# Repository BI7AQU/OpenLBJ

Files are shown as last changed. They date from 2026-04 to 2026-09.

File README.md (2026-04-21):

# [OpenLBJ](https://github.com/BI7AQU/OpenLBJ)
- A LBJ message receiver based on ESP32-PICO-D4 and [Ai-Thinker Ra-01H](https://docs.ai-thinker.com/en/Ra-01H/index.html) (SX1276 RF chip).
- This project aims to receive the Chinese Railway Train Proximity Alarm (on 821.2375MHz following POCSAG protocol) messages transmitted by on board LBJ systems through CIR.
- This hardware is designed to be compatible with the **[SX1276_Receive_LBJ](https://github.com/FLN1021/SX1276_Receive_LBJ)** firmware.
- The design of this project is based on the [TTGO LoRa32 ESP32 dev board](https://github.com/Xinyuan-LilyGO/LilyGo-LoRa-Series/blob/master/schematic/T3_V1.6.1.pdf), and it integrates the functions of real-time clock (RTC), button menu and buzzer alarm.

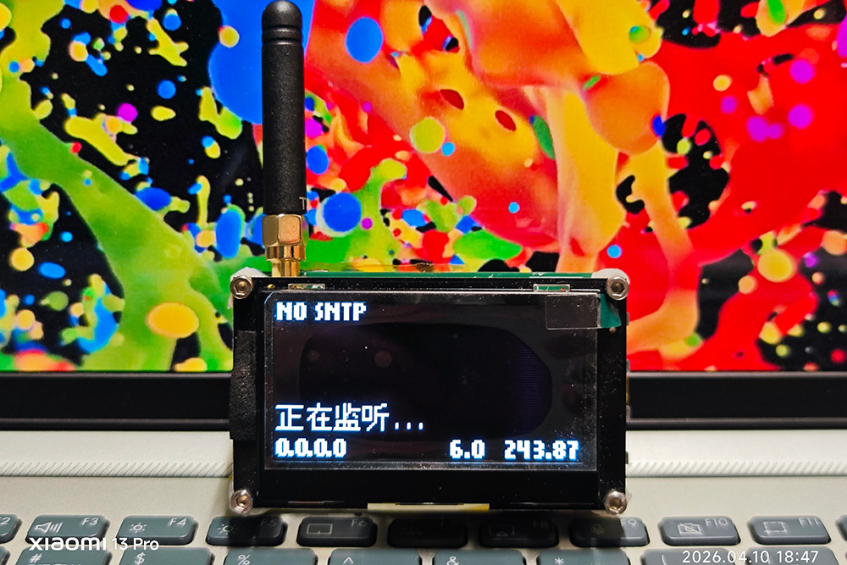
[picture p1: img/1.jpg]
Receiving...


## Notice

This project is intended for learning 2FSK signal reception modulation and POCSAG code decoding.

Please ensure that this complies with local laws and regulations when in use, and assume responsibility for any risks.

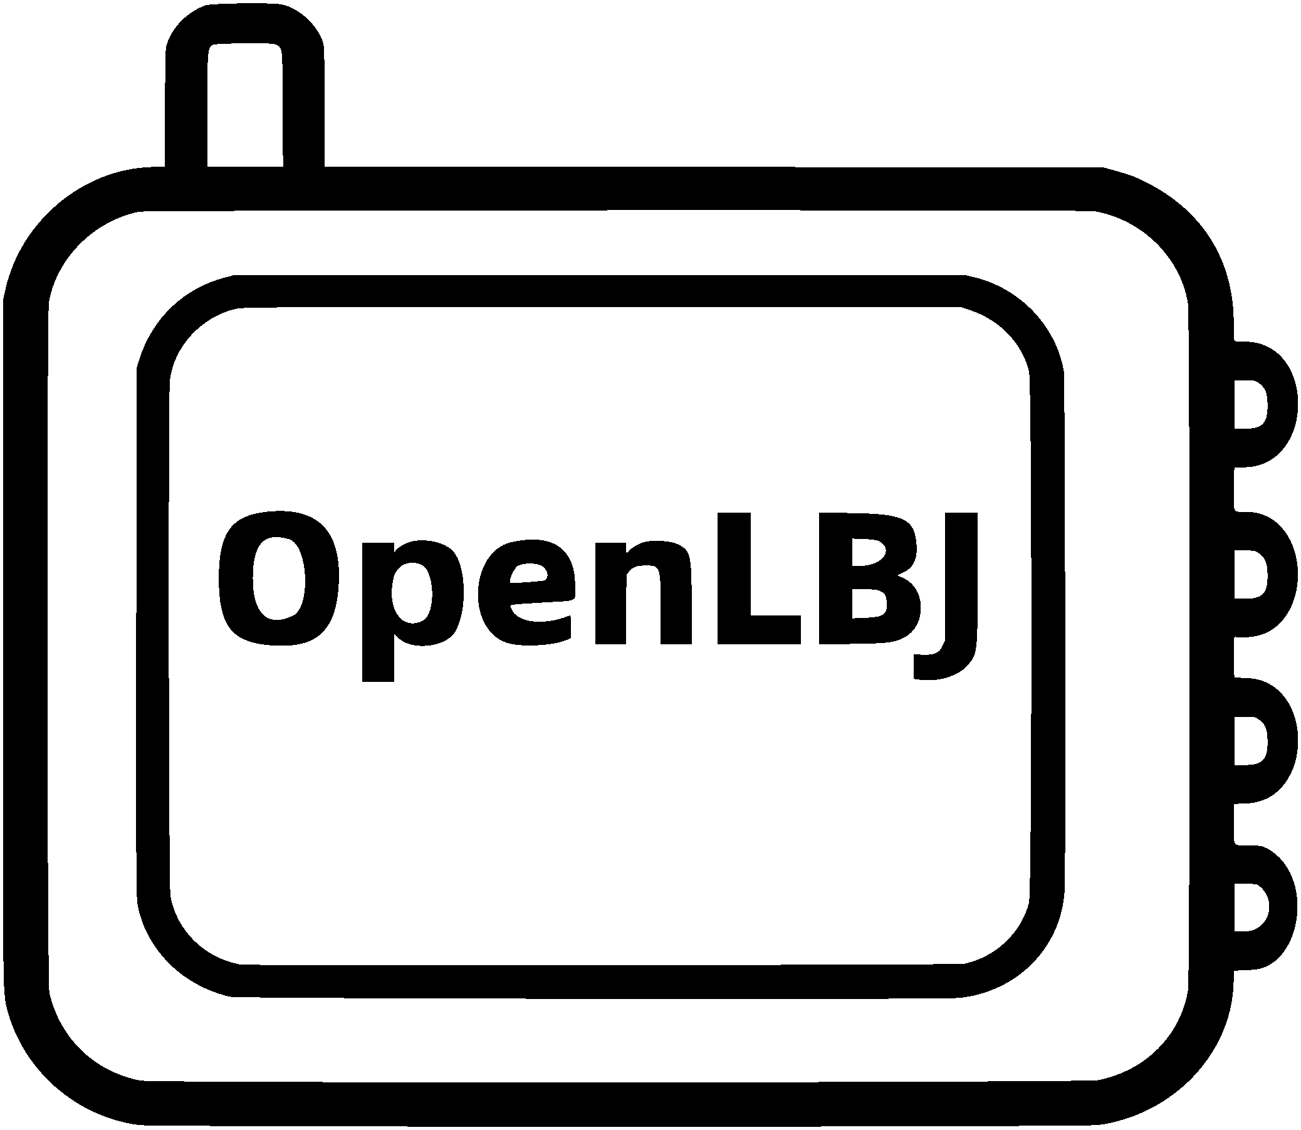
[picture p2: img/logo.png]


## Hardware
The schematic of this board can be found in the folder.

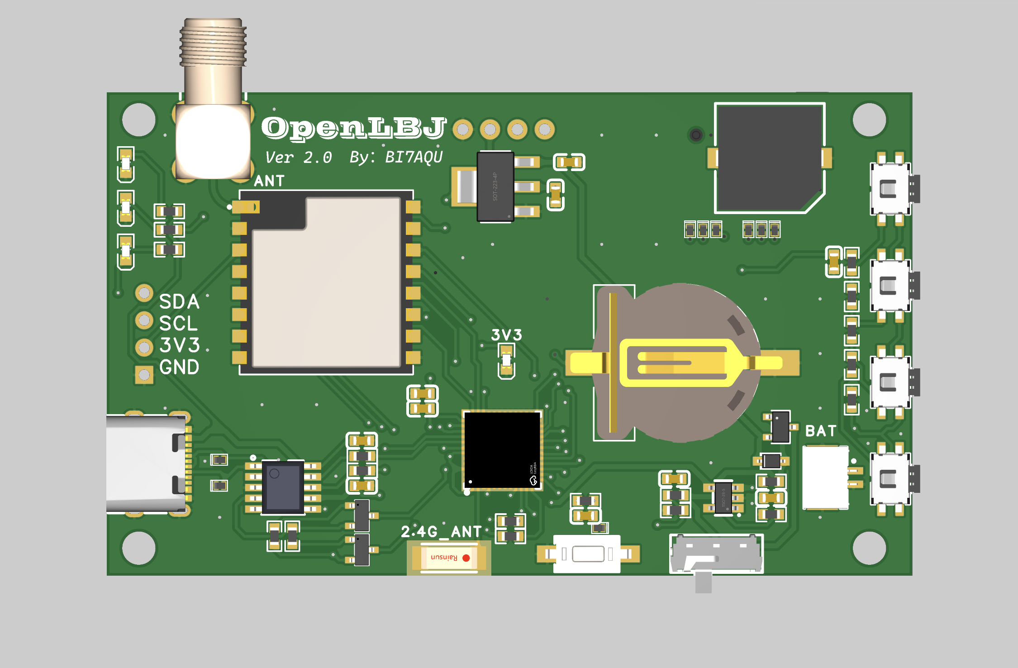
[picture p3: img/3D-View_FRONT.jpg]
Front


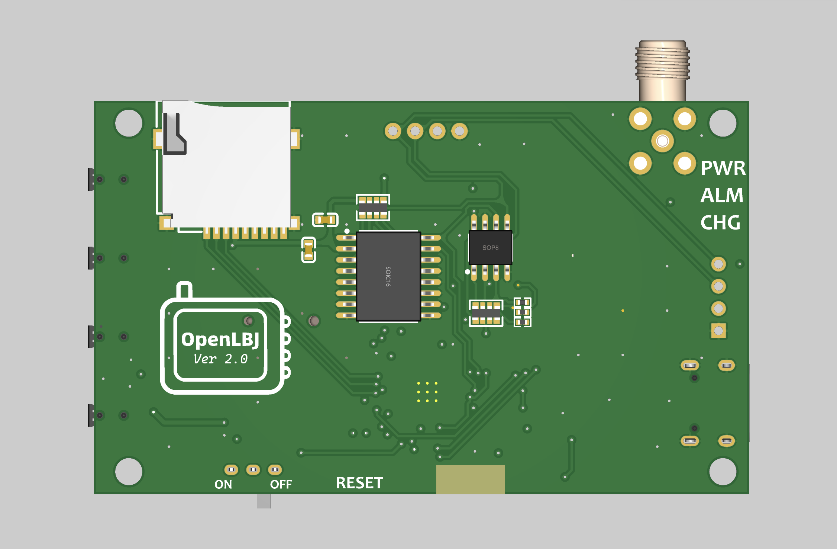
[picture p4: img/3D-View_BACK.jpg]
Back


## Known Issues
- Takes a very long time to startup if a large number of files are in TF card.
- TF card hot-plug is **NOT** supported. Unplug while power on will cause crash after next message receive.
- Partially decoded or corrupted message will show on display.

Sometimes the received messages may be corrupt, partially decoded or wrongly corrected, thus may display unreliable results.
If `<NUL>`, `NA`, `********` or part of these characters shows up, it means this part of the message is corrupted.

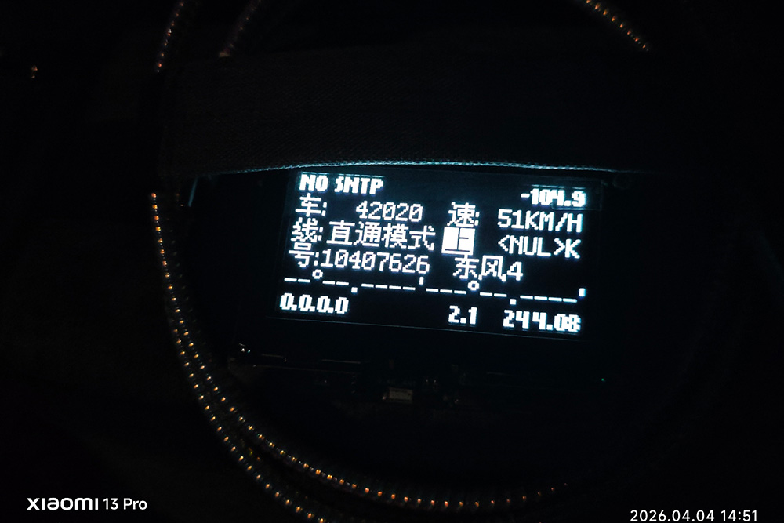
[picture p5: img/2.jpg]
Decoding...


## License
[GPL-3.0 license](https://github.com/BI7AQU/OpenLBJ#GPL-3.0-1-ov-file)

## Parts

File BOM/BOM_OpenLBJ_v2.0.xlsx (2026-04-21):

烧录说明：按键需调试修改主程序中ADC值。
焊接说明：1、若无需RTC功能，正面电池和背面除TF卡座以外的元器件均不焊接；2、ULC0511二极管可不焊；3、两种OLED屏幕二选一即可。
No. | Quantity | Comment | Designator | Footprint | Value | Manufacturer Part | Manufacturer | Supplier Part
1 | 1 | CR1220-2 | B1 | BAT-SMD_CR1220-2 |  | CR1220-2 | QIJEY | C70381
2 | 8 | 100nF | C1,C3,C4,C5,C6,C7,C10,C12 | C0603 | 100nF | CC0603KRX7R9BB104 | YAGEO(国巨) | C14663
3 | 3 | 10uF | C2,C9,C11 | C0603 | 10uF | CC0603KRX5R6BB106 | YAGEO(国巨) | C326057
4 | 1 | 1uF | C8 | C0603 | 1uF | CC0603KRX5R8BB105 | YAGEO(国巨) | C14664
5 | 1 | WAFER-GH1.25-2PWB | CN1 | CONN-TH_2P-P1.25_XUNPU_WAFER-GH1.25-2PWB |  | WAFER-GH1.25-2PWB | XUNPU(讯普) | C3029377
6 | 9 | ULC0511CDN | D1,D2,D3,D4,D5,D6,D7,D8,D9 | X1-DFN1006-2_L1.0-W0.6-RD |  | ULC0511CDN | Leiditech(雷卯电子) | C384841
7 | 1 | BAT20JFILM | D10 | SOD-323_L1.8-W1.3-LS2.5-RD |  | BAT20JFILM | ST(意法半导体) | C155590
8 | 1 | AN2051-245 | L1 | ANT2051 |  | AN2051-245 | Rainsun(霖昱微) | C99727
9 | 4 | GL0603UR01 | LED1,LED2,LED3,LED4 | LED0603-FD |  | GL0603UR01 | Guiguang light(桂光光电) | C51933292
10 | 1 | HS242L03W2C01 | OLED1 | LCD-TH_4P-L72.0-W43.0-P2.54_HS242L03W2C01 |  | HS242L03W2C01 | HS(汉昇) | C7466001
11 | 1 | HS96L03W2C03 | OLED2 | OLED-TH_L27.8-W27.2-P2.54_C9900033791 |  | HS96L03W2C03 | HS(汉昇) | C5248080
12 | 2 | S8050 | Q1,Q2 | SOT-23-3_L2.9-W1.3-P1.90-LS2.3-BR |  | S8050 | R+O(宏嘉诚) | C20069125
13 | 1 | SI2307A | Q3 | SOT-23-3_L3.0-W1.7-P0.95-LS2.9-BR |  | SI2307A | UMW(友台半导体) | C347490
14 | 2 | 470Ω | R1,R2 | R0603 | 470Ω | RC0603JR-07470RL | YAGEO(国巨) | C114433
15 | 6 | 10kΩ | R3,R6,R7,R15,R16,R17 | R0603 | 10kΩ | RC0603FR-0710KL | YAGEO(国巨) | C98220
16 | 2 | 22Ω | R4,R5 | R0603 | 22Ω | RC0603FR-0722RL | YAGEO(国巨) | C107701
17 | 2 | 2kΩ | R8,R9 | R0603 | 2kΩ | RC0603FR-072KL | YAGEO(国巨) | C105576
18 | 2 | 100kΩ | R10,R11 | R0603 | 100kΩ | RC0603FR-07100KL | YAGEO(国巨) | C14675
19 | 3 | 0Ω | R12,R13,R14 | R0402 | 0Ω | RC0402FR-070RL | YAGEO(国巨) | C106231
20 | 1 | 2kΩ | R18 | R0603 | 2kΩ | RC0603JR-072KL | YAGEO(国巨) | C105581
21 | 2 | 4.7kΩ | RN1,RN2 | RES-ARRAY-SMD_0603-8P-L3.2-W1.6-BL | 4.7kΩ | 4D03WGJ0472T5E | UNI-ROYAL(厚声) | C1980
22 | 1 | TS-1101-C-W | SW1 | SW-SMD_L6.0-W3.3-LS8.0 |  | TS-1101-C-W | XKB Connection(中国星坤) | C318938
23 | 1 | MK-12D18-G040 | SW2 | SW-TH_MK-12D18-G040 |  | MK-12D18-G040 | G-Switch(品赞) | C963202
24 | 4 | TS-3547SLM | SW7,SW8,SW9,SW10 | SW-SMD_TS-3547SLM |  | TS-3547SLM | 康深 | C47734524
25 | 1 | Ra-01H | U1 | WIRELM-SMD_RA-01H |  | Ra-01H | Ai-Thinker(安信可) | C503593
26 | 1 | ESP32-PICO-D4 | U2 | LGA-48_L7.0-W7.0-P0.50-BL-EP5.4 |  | ESP32-PICO-D4 | ESPRESSIF(乐鑫) | C193707
27 | 1 | HX TF PUSH | U3 | TF-SMD_TF-PUSH |  | HX TF PUSH | hanxia(韩下) | C5184837
28 | 1 | AMS1117-3.3 | U4 | SOT-223-4_L6.5-W3.5-P2.30-LS7.0-BR |  | AMS1117-3.3 | UMW(友台半导体) | C347222
29 | 1 | CH340K | U5 | ESOP-10_L4.9-W3.9-P1.00-LS6.2-BL-EP |  | CH340K | WCH(南京沁恒) | C968586
30 | 1 | TP4054 | U6 | TSOT-23-5_L2.9-W1.6-P0.95-LS2.8-BR |  | TP4054 | UMW(友台半导体) | C668215
31 | 1 | AT24C02 | U7 | SOP-8_L5.0-W4.0-P1.27-LS6.0-BL |  | AT24C02 | IDCHIP(英锐芯) | C688857
32 | 1 | 10GHz | U8 | SMA-TH_SMA-KWE | 10GHz | SMA-KWE | cntitle(中戈泰斗) | C20415790
33 | 1 | 2.7kHz | U9 | BUZ-SMD_L9.6-W9.6-LS10.0-R | 2.7kHz | HYG-9605B 3V | HYDZ(华宇) | C7544818
34 | 1 | DS3231SN#T&R | U12 | SOIC-16_L10.3-W7.5-P1.27-LS10.3-BL |  | DS3231SN#T&R | ADI(亚德诺)/MAXIM(美信) | C9866
35 | 4 | 2kΩ | U13,U14,U15,U16 | R0603 | 2kΩ | 0603WAF2001T5E | UNI-ROYAL(厚声) | C22975
36 | 1 | TYPE-C 16PIN 2MD(073) | USB1 | USB-C-SMD_TYPE-C-6PIN-2MD-073 |  | TYPE-C 16PIN 2MD(073) | SHOU HAN(首韩) | C2765186

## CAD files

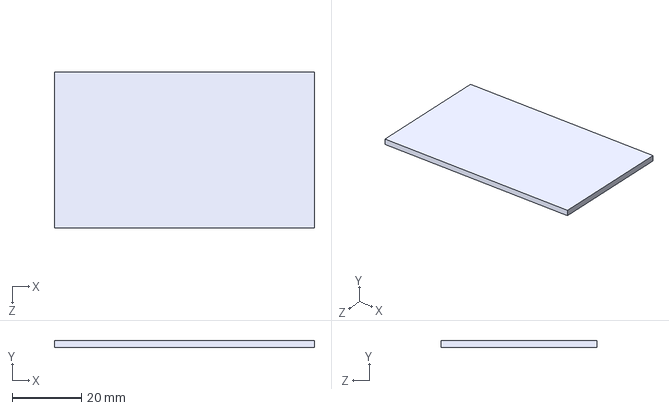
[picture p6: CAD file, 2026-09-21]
SHELL/背盖.STEP
75.0 x 2.00 x 45.0 mm

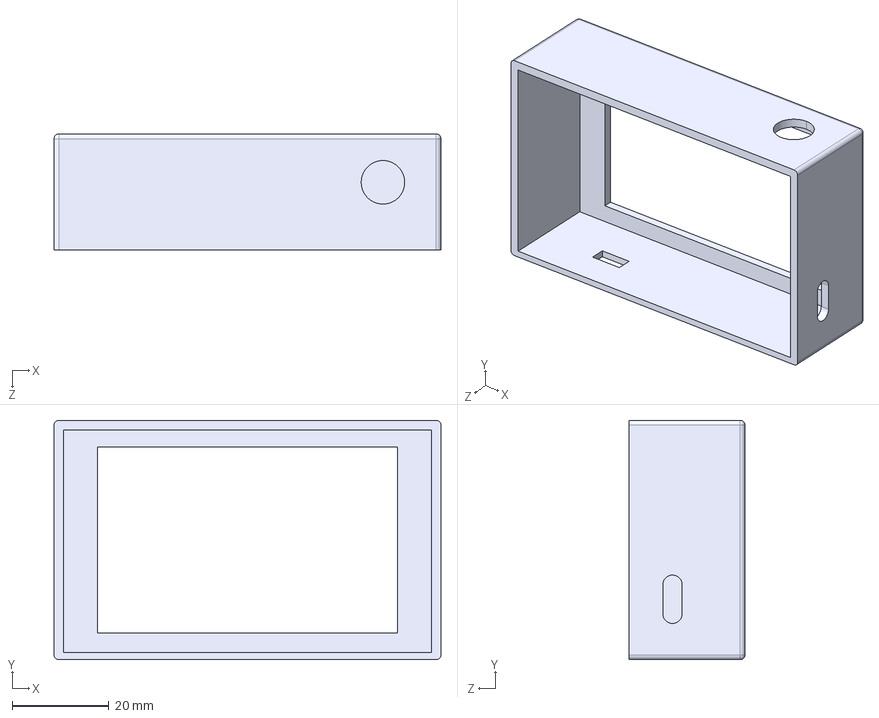
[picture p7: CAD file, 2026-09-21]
SHELL/外壳.STEP
80.0 x 49.5 x 24.0 mm

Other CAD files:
SHELL/外壳.SLDPRT
SHELL/背盖.SLDPRT

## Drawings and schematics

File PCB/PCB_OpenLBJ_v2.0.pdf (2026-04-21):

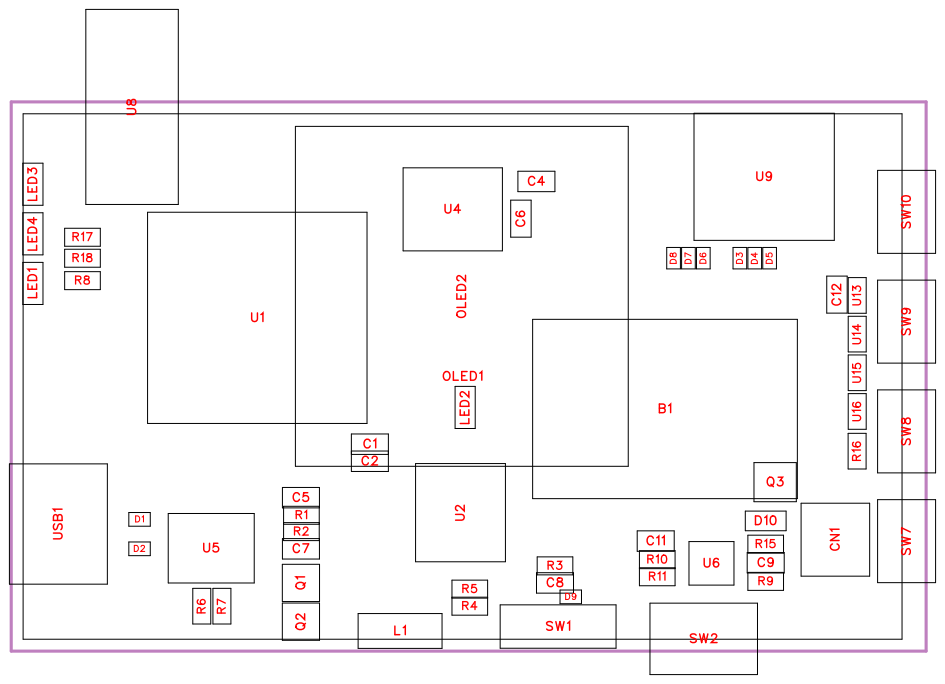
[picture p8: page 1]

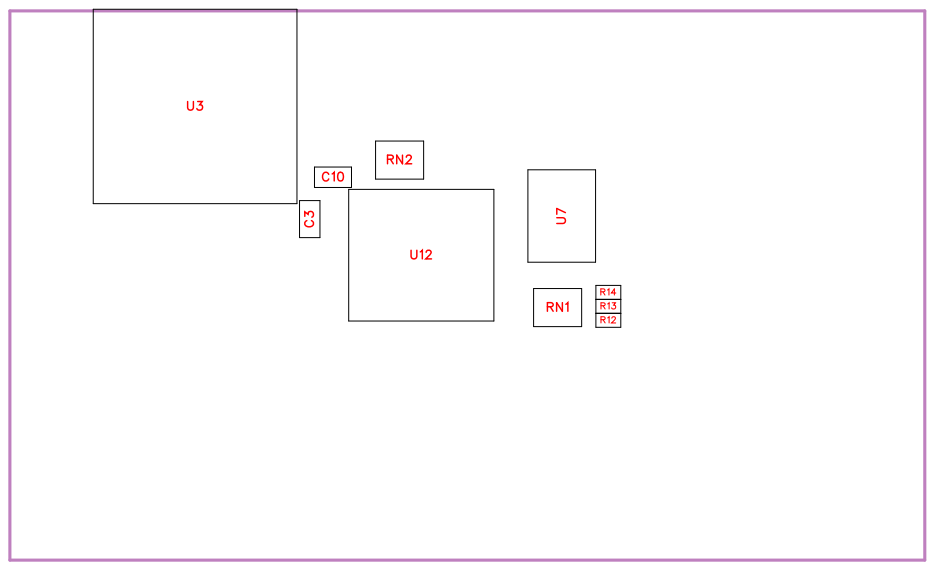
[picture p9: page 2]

No. | Quantity | Comment | Designator | Footprint | Value | Manufacturer Part | Manufacturer | Supplier Part | Supplier
1 | 1 | CR1220-2 | B1 | BAT-SMD_C R1220-2 | | CR1220-2 | QIJEY | C70381 | LCSC
2 | 8 | 100nF | C1,C3,C4,C5,C6,C7,C10,C 12 | C0603 | 100nF | CC0603KRX 7R9BB104 | YAGEO(国巨 ) | C14663 | LCSC
3 | 3 | 10uF | C2,C9,C11 | C0603 | 10uF | CC0603KRX 5R6BB106 | YAGEO(国巨 ) | C326057 | LCSC
4 | 1 | 1uF | C8 | C0603 | 1uF | CC0603KRX 5R8BB105 | YAGEO(国巨 ) | C14664 | LCSC
5 | 1 | WAFER-GH1 .25-2PWB | CN1 | CONN-TH_2 P-P1.25_XU NPU_WAFE R-GH1.25-2P WB | | WAFER-GH1 .25-2PWB | XUNPU(讯普 ) | C3029377 | LCSC
6 | 9 | ULC0511C | D1,D2,D3,D4,D5,D6,D7,D8, D9 | X1-DFN1006 -2_L1.0-W0.6 -RD | | ULC0511C | Leiditech( 雷 卯电子 ) | C384841 | LCSC
7 | 1 | BAT20J | D10 | SOD-323_L1 .8-W1.3-LS2. 5-RD | | BAT20J | ST(意法半导 体) | C155590 | LCSC
8 | 1 | AN2051-245 | L1 | ANT2051 | | AN2051-245 | Rainsun(霖昱 微) | C99727 | LCSC
9 | 1 | ORANGE | LED1 | LED0603-FD | | ORANGE | Guiguang lig ht(桂光光电 ) | C51933292 | LCSC
10 | 1 | BLUE | LED2 | LED0603-FD | | BLUE | Guiguang lig ht(桂光光电 ) | C51933292 | LCSC
11 | 1 | RED | LED3 | LED0603-FD | | RED | Guiguang lig ht(桂光光电 ) | C51933292 | LCSC
12 | 1 | GREEN | LED4 | LED0603-FD | | GREEN | Guiguang lig ht(桂光光电 ) | C51933292 | LCSC
13 | 1 | HS242L03W 2C01 | OLED1 | LCD-TH_4P-L72.0-W43.0-P2.54_HS24 2L03W2C01 | | HS242L03W 2C01 | HS(汉昇 ) | C7466001 | LCSC
14 | 1 | HS96L03W2 C03 | OLED2 | OLED-TH_L2 7.8-W27.2-P 2.54_C99000 33791 | | HS96L03W2 C03 | HS(汉昇 ) | C5248080 | LCSC
15 | 2 | S8050 | Q1,Q2 | SOT-23-3_L2 .9-W1.3-P1.9 0-LS2.3-BR | | S8050 | R+O(宏嘉诚 ) | C20069125 | LCSC
16 | 1 | SI2307A | Q3 | SOT-23-3_L3 .0-W1.7-P0.9 5-LS2.9-BR | | SI2307A | UMW(友台半 导体 ) | C347490 | LCSC
17 | 2 | 470 | R1,R2 | R0603 | 470 | RC0603JR-0 7470RL | YAGEO(国巨 ) | C114433 | LCSC
18 | 6 | 10k | R3,R6,R7,R15,R16,R17 | R0603 | 10k | RC0603FR-0 710KL | YAGEO(国巨 ) | C98220 | LCSC
19 | 2 | 22 | R4,R5 | R0603 | 22 | RC0603FR-0 722RL | YAGEO(国巨 ) | C107701 | LCSC

20 | 2 | 2k | R8,R9 | R0603 | 2k | RC0603FR-0 72KL | YAGEO(国巨 ) | C105576 | LCSC
21 | 2 | 100k | R10,R11 | R0603 | 100k | RC0603FR-0 7100KL | YAGEO(国巨 ) | C14675 | LCSC
22 | 3 | 0 | R12,R13,R14 | R0402 | 0 | RC0402FR-0 70RL | YAGEO(国巨 ) | C106231 | LCSC
23 | 1 | 2k | R18 | R0603 | 2k | RC0603JR-0 72KL | YAGEO(国巨 ) | C105581 | LCSC
24 | 2 | 4.7k | RN1,RN2 | RES-ARRAY -SMD_0603-8P-L3.2-W1. 6-BL | 4.7k | 4D03WGJ04 72T5E | UNI-ROYAL( 厚声 ) | C1980 | LCSC
25 | 1 | TS-1101-C- W | SW1 | SW-SMD_L6 .0-W3.3-LS8. 0 | | TS-1101-C- W | XKB Connect ivity(中国星坤 ) | C318938 | LCSC
26 | 1 | MK-12D18-G 040 | SW2 | SW-TH_MK-12D18-G040 | | MK-12D18-G 040 | G-Switch( 品 赞 ) | C963202 | LCSC
27 | 4 | TS-3547SLM | SW7,SW8,SW9,SW10 | SW-SMD_TS -3547SLM | | TS-3547SLM | 康深 | C47734524 | LCSC
28 | 1 | Ra-01H | U1 | WIRELM-SM D_RA-01H | | Ra-01H | Ai-Thinker( 安 ) 信可 | C503593 | LCSC
29 | 1 | ESP32-PICO -D4 | U2 | LGA-48_L7.0 -W7.0-P0.50-BL-EP5.4 | | ESP32-PICO -D4 | ESPRESSIF( ) 乐鑫 | C193707 | LCSC
30 | 1 | HX TF PUSH | U3 | TF-SMD_TF-PUSH | | HX TF PUSH | hanxia(韩下 ) | C5184837 | LCSC
31 | 1 | AMS1117-3. 3 | U4 | SOT-223-4_L 6.5-W3.5-P2. 30-LS7.0-BR | | AMS1117-3. 3 | UMW(友台半 导体 ) | C347222 | LCSC
32 | 1 | CH340K | U5 | ESOP-10_L4 .9-W3.9-P1.0 0-LS6.2-BL-E P | | CH340K | WCH(南京沁 恒) | C968586 | LCSC
33 | 1 | TP4054 | U6 | TSOT-23-5_ L2.9-W1.6-P 0.95-LS2.8-B R | | TP4054 | UMW(友台半 导体 ) | C668215 | LCSC
34 | 1 | AT24C02 | U7 | SOP-8_L5.0-W4.0-P1.27-LS6.0-BL
35 | 1 | 10GHz | U8 | SMA-TH_SM A-KWE | 10GHz | SMA-KWE | cntitle(中戈泰 斗) | C20415790 | LCSC
36 | 1 | 2.7kHz | U9 | BUZ-SMD_L 9.6-W9.6-LS 10.0-R | 2.7kHz | HYG-9605B 3V | HYDZ(华宇 ) | C7544818 | LCSC
37 | 1 | DS3231SN# T&R | U12 | SOIC-16_L1 0.3-W7.5-P1. 27-LS10.3-B L | | DS3231SN# T&R | ADI(亚德诺)/ MAXIM(美信 ) | C9866 | LCSC
38 | 4 | 2k | U13,U14,U15,U16 | R0603 | 2k

39

1 | TYPE-C
16PIN
2MD(073)
USB1 | USB-C-SMD
_TYPE-C-6PI
N-2MD-073

TYPE-C
16PIN
2MD(073)

SHOU
HAN(首韩

)

C2765186 LCSC

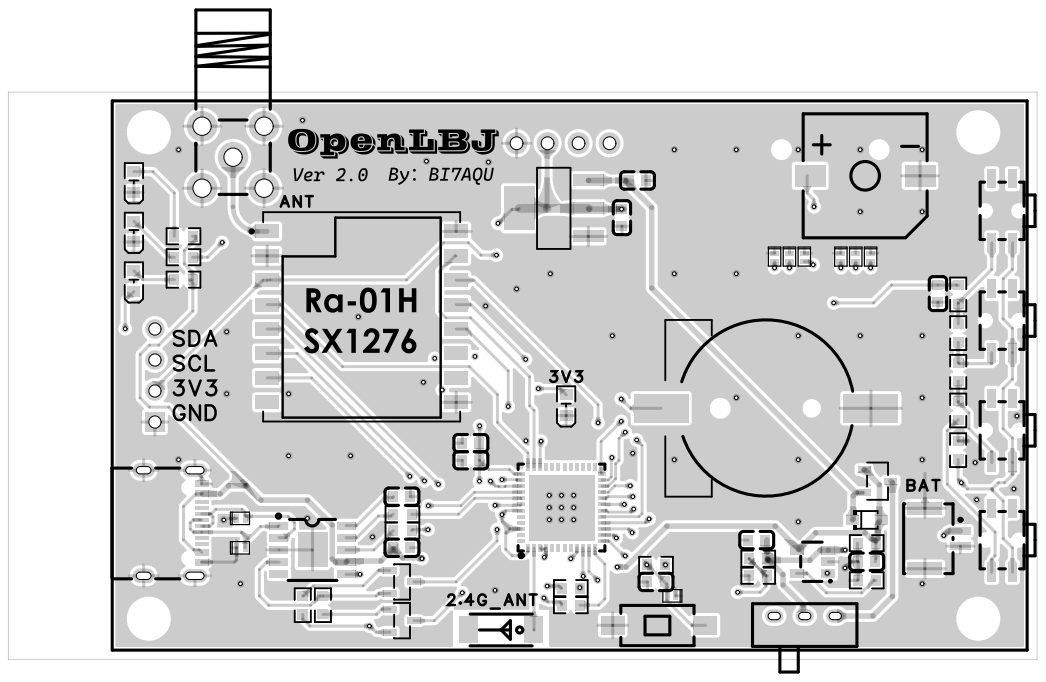
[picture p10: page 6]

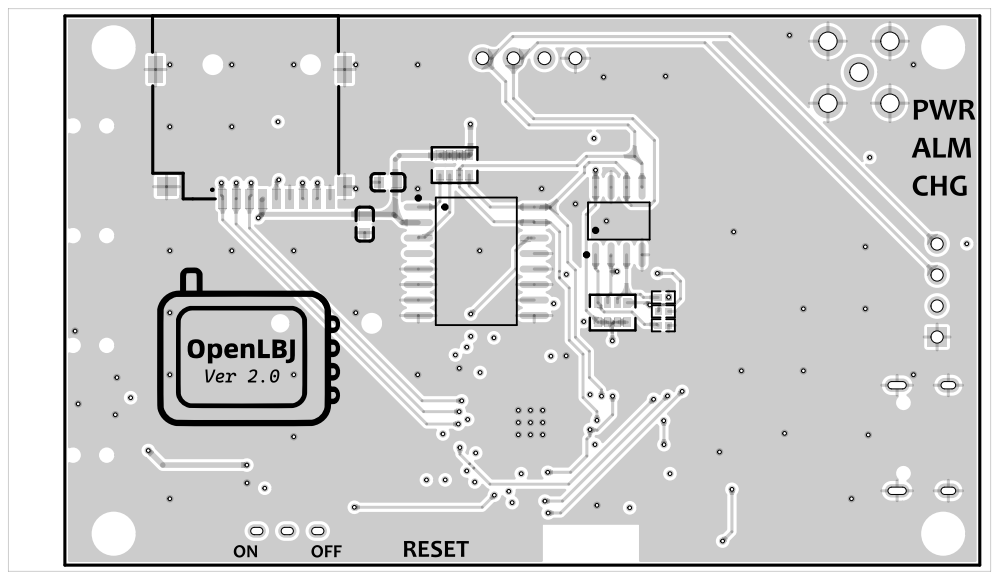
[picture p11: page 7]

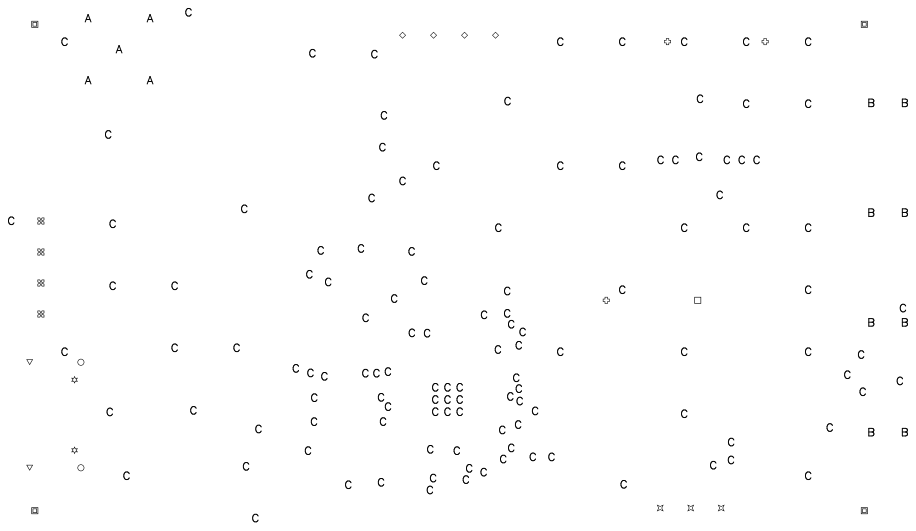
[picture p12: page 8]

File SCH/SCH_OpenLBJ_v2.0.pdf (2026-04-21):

# VDD_SDIO 26 IO17 27 SD2 28 SD3 29 CMD 30 CLK 31 SD0 32 SD1 33 IO5 34 IO18 35 IO23 36

Core | LORA

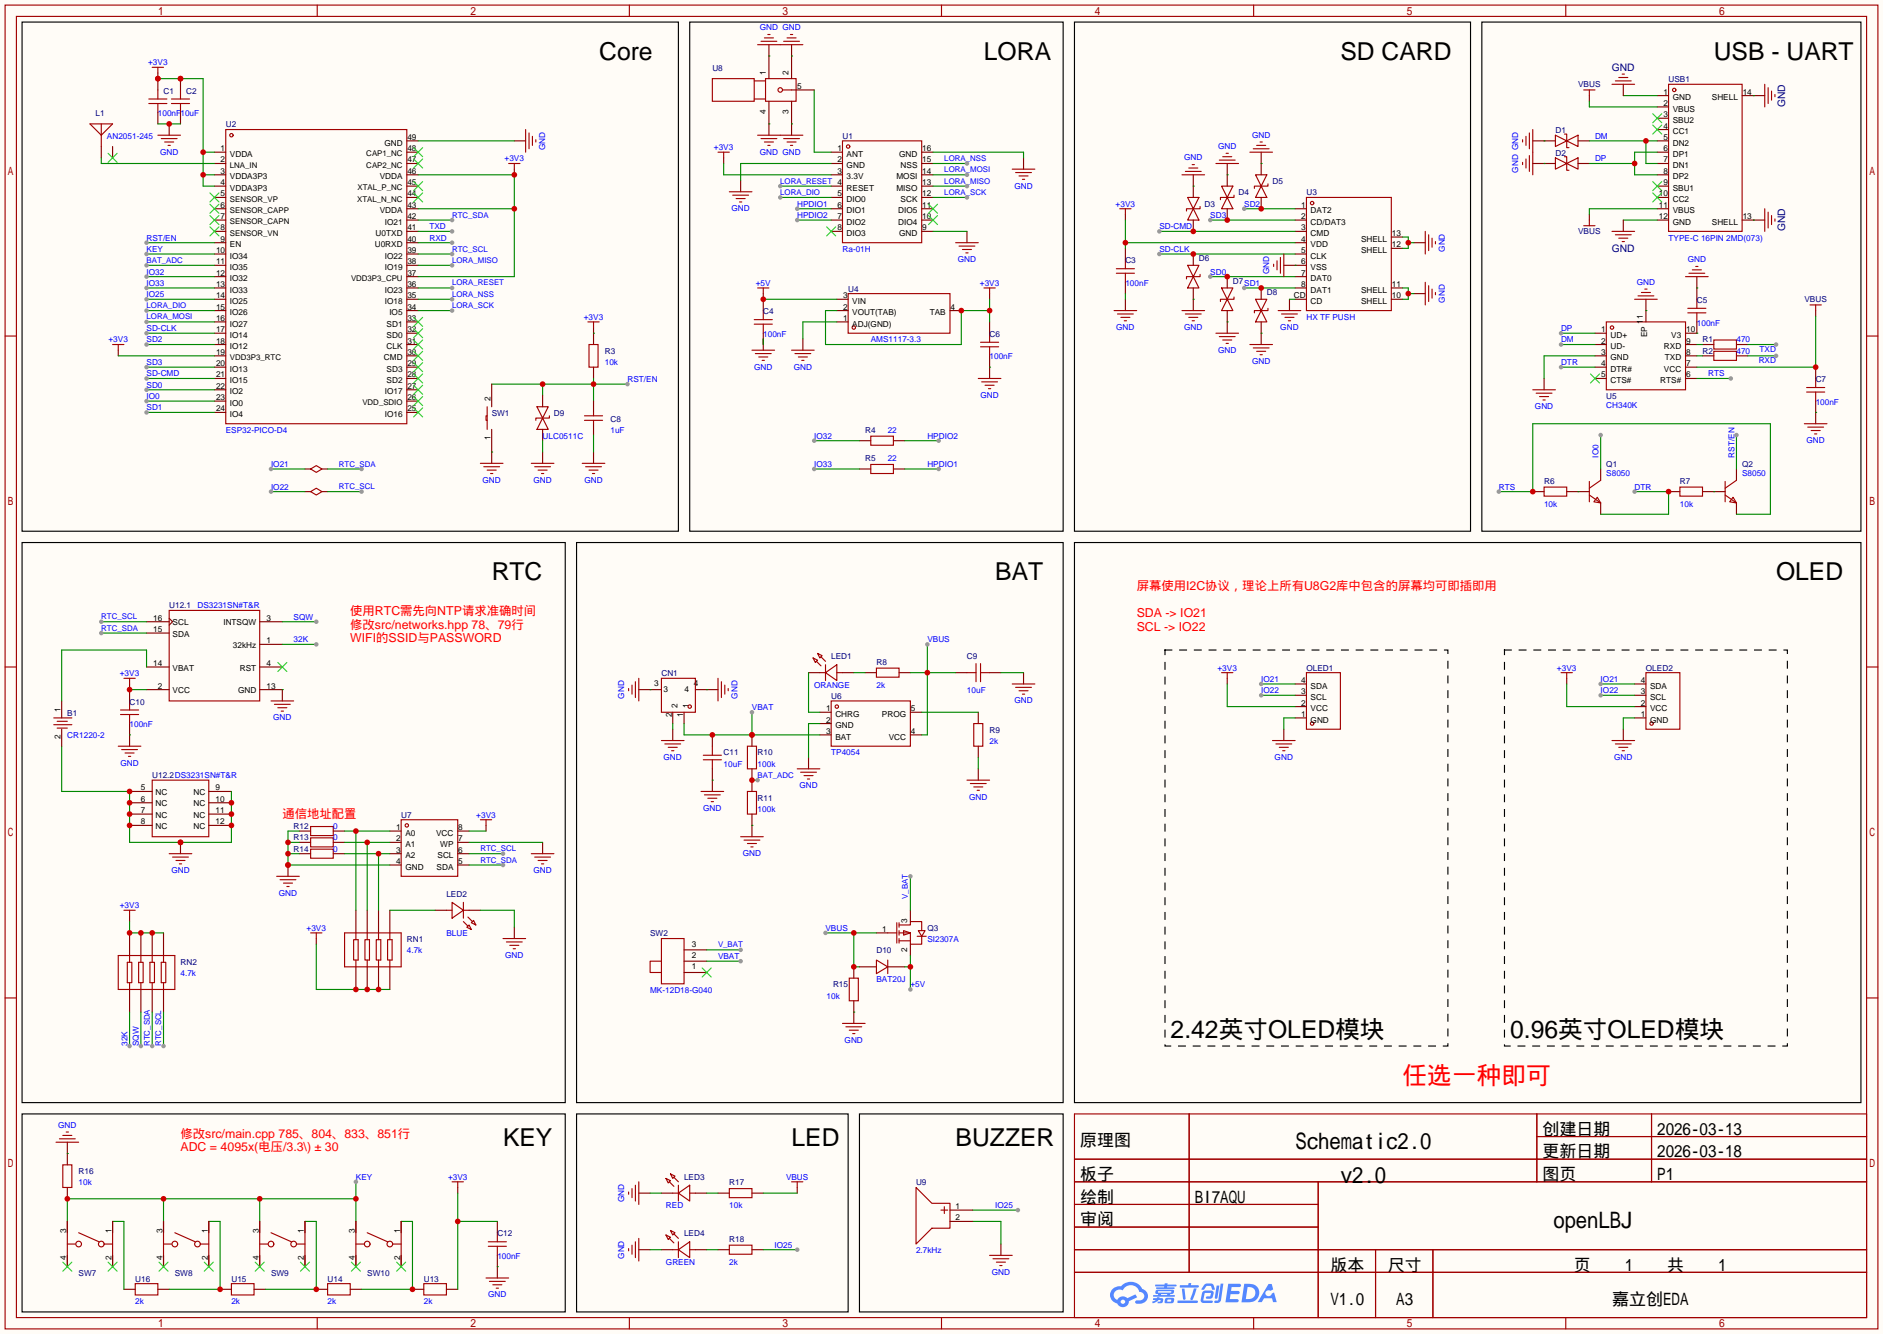
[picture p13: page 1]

原理图 | Schematic2.0 | 创建日期 | 2026-03-13

更新日期 | 2026-03-18

板子 | v2.0 | 图页 | P1
绘制 | BI7AQU | openLBJ
审阅

V1.0 | A3 | 嘉立创EDA

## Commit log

2026-04-21 update BOM
    [BOM_OpenLBJ_v2.0.xlsx]
2026-09-21 add shell(case)
    [外壳.SLDPRT, 外壳.STEP, 背盖.SLDPRT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]
